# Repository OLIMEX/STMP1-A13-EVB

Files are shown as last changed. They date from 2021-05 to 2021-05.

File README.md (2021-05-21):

# STMP1-A13-EVB
Evaluation board for STMP15x-SOM and A13-SOM System on modules

Product page: https://www.olimex.com/Products/SOM/STMP1/STMP1-A13--EVB/open-source-hardware

## License
* Hardware is released under CERN OHL v1.2 license
* Software is released under GPL3 License
* Documentation is released under CC BY-SA 3.0

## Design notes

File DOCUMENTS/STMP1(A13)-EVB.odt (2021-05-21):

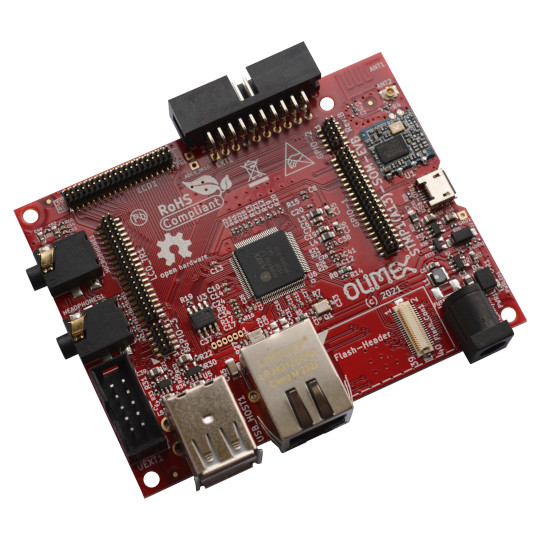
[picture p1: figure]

STMP1(A13)-EVB

User Manual

Rev.1.0 May 2021

olimex.com

# Overview

STMP1 (https://www.olimex.com/Products/SOM/STMP1/STMP1-A13--EVB/open-source-hardware)(A13) (https://www.olimex.com/Products/SOM/STMP1/STMP1-A13--EVB/open-source-hardware)- (https://www.olimex.com/Products/SOM/STMP1/STMP1-A13--EVB/open-source-hardware)EVB (https://www.olimex.com/Products/SOM/STMP1/STMP1-A13--EVB/open-source-hardware) is evaluation board for STMP15x-SOM (https://www.olimex.com/Products/SOM/STMP1/STMP157-SOM-512/) or A13-SOM (https://www.olimex.com/Products/SOM/A13/) System On Module running Linux mainline Kernel and Uboot on ST Microelectronics industrial grade Dual Core Cortex-A7 ARM SOC.

As A13-SOM (https://www.olimex.com/Products/SOM/A13/) and STMP15x-SOM (https://www.olimex.com/Products/SOM/STMP1/STMP157-SOM-512/) share same pinout this evaluation board is suitable also for A13-SOM (https://www.olimex.com/Products/SOM/A13/) System On Module.

Top view:

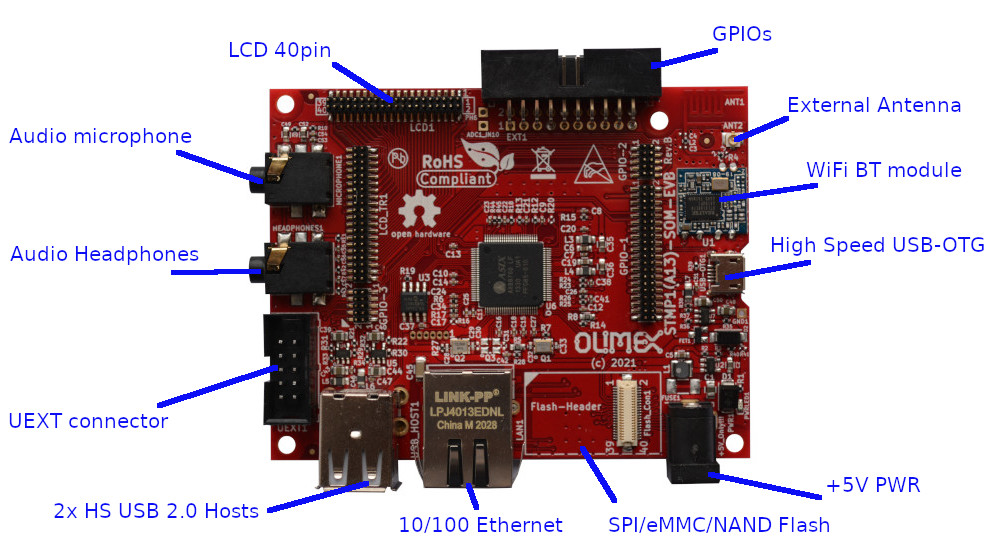
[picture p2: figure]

## General information

STM32MP15X (https://www.st.com/en/microcontrollers-microprocessors/stm32mp1-series.html) SOC are Dual-core Arm Cortex-A7 running up to 800 MHz and Cortex-M4 at 209 MHz combined with a LCD interface, dedicated 3D graphics processing unit (GPU).

STMP1 (https://www.olimex.com/Products/SOM/STMP1/STMP1-A13--EVB/open-source-hardware)(A13) (https://www.olimex.com/Products/SOM/STMP1/STMP1-A13--EVB/open-source-hardware)- (https://www.olimex.com/Products/SOM/STMP1/STMP1-A13--EVB/open-source-hardware)EV (https://www.olimex.com/Products/SOM/STMP1/STMP1-A13--EVB/open-source-hardware)B (https://www.olimex.com/Products/SOM/STMP1/STMP151-SOM-256/) demo evaluation board is produced only in commercial temperature grade 0-70C.

## Order codes

STMP1 (https://www.olimex.com/Products/SOM/STMP1/STMP1-A13--EVB/open-source-hardware)(A13) (https://www.olimex.com/Products/SOM/STMP1/STMP1-A13--EVB/open-source-hardware)- (https://www.olimex.com/Products/SOM/STMP1/STMP1-A13--EVB/open-source-hardware)EV (https://www.olimex.com/Products/SOM/STMP1/STMP1-A13--EVB/open-source-hardware)B (https://www.olimex.com/Products/SOM/STMP1/STMP151-SOM-256/) only evaluation board for STMP15x-SOM (https://www.olimex.com/Products/SOM/STMP1/STMP157-SOM-512/) or A13-SOM (https://www.olimex.com/Products/SOM/A13/), does not include SOM module which have to be bough separately

## STMP1(A13)-EVB Features

- 0.05 inch (1.27 mm) connectors for STMP15x-SOM (https://www.olimex.com/Products/SOM/STMP1/STMP157-SOM-512/) or A13-SOM (https://www.olimex.com/Products/SOM/A13/)
- Two High Speed USB 2.0 Hosts
- High Speed USB 2.0 OTG
- 10/100Mb Ethernet connector
- WiFi / Bluetooth module with PCB antenna and option for external antenna
- Flash module connector for: SPI, eMMC, NAND Flash options
- 3.5mm Audio jack for microphone
- 3.5mm Audio jack for headphones
- UEXT connector
- GPIO connector
- 40 pin 0.05 inch (1.27 mm) step connector compatible with LCD-OLinuXino
- Power supply connector 5VDC

# Power supply

STMP1 (https://www.olimex.com/Products/SOM/STMP1/STMP1-A13--EVB/open-source-hardware)(A13) (https://www.olimex.com/Products/SOM/STMP1/STMP1-A13--EVB/open-source-hardware)- (https://www.olimex.com/Products/SOM/STMP1/STMP1-A13--EVB/open-source-hardware)E (https://www.olimex.com/Products/SOM/STMP1/STMP1-A13--EVB/open-source-hardware)VB (https://www.olimex.com/Products/SOM/STMP1/STMP1-A13--EVB/open-source-hardware) requires +5V, 0.2A to operate.

Do not apply more than 5V as this would damage the board.

Power consumption (including SOM module) is:

- around 0.4 A during boot
- around 0.6A when working at full speed
- around 1.2A when working at full speed and charge the LiPo battery

# Connectors

## LCD

RGB LCD signals and I2C connector to digital touch panel interface.

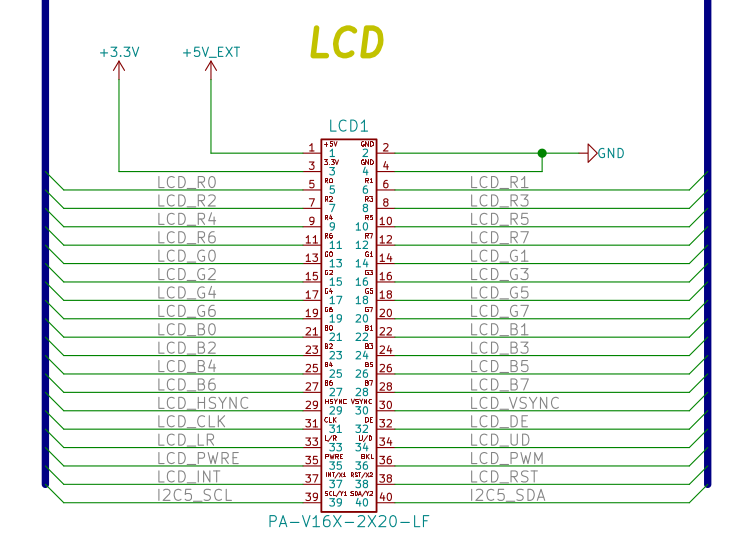
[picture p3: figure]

## GPIO

Right angle 20 pin connector with 2x I2C, UART, SDMMC, 2 GPIO, NRST, +3.3V and GND.

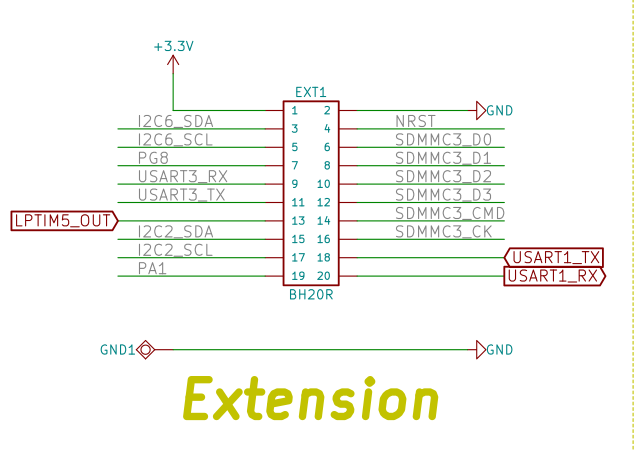
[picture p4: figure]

## UEXT

UEXT (https://www.olimex.com/Products/Modules/) connector for attaching different modules and sensors to SPI, UART, I2C:

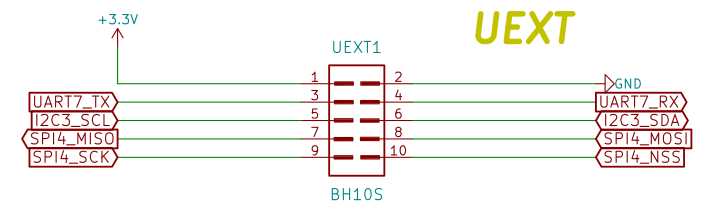
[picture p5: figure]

# Revision History

Revision 1.0 May 2021

# Contact information

Headquarters and Factory address:

OLIMEX Ltd

ul. Pravda 2

Plovdiv 4000

BULGARIA

Sales: sales@olimex.com

Technical Support: support@olimex.com

Corporate Website: www.olimex.com

For latest news and developments - follow our

- Blog (https://olimex.wordpress.com/)
- GitHub (https://github.com/OLIMEX)
- Twitter (https://twitter.com/olimex)
- Facebook (https://www.facebook.com/OLINUXINO/)
- Mastodon (https://mastodon.social/@olimex)
- Pluspora (https://pluspora.com/people/604855503b7f01377c23005056264835)
- IRC (https://webchat.freenode.net/#olimex)
- flicr (https://www.flickr.com/photos/olimex/)

11 STMP1(A13)-EVB Rev 1.0 www.olimex.com

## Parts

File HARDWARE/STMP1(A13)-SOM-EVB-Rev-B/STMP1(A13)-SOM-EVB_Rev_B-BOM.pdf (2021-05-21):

01/18/2021 | STMP1(A13)-SOM-EVB_Rev_B-BOM | 13:04:04
Quantity | Designation | Package | Designator
1 | 0R/R0402(Default_1-2_Populated) | R0402 | R4
1 | 0R/R0402 | L0402 | L2
5 | 22R/R0402 | R0402 | R11,R19,R42,R43,R45
4 | 49.9R/1%/R0402 | R0402 | R23,R24,R25,R26
2 | 330R/R0402 | R0402 | R27,R28
1 | 680R/1%/R0402 | R0402 | R6
1 | 1.1k/1%/R0402 | R0402 | R3
4 | 2.2k/R0402 | R0402 | R1,R9,R10,R44
5 | 4.7k/R0402 | R0402 | R15,R18,R33,R34,R38
1 | 4.99k/1%/R0402 | R0402 | R2
12 | 10k/R0402 | R0402 | R12,R13,R14,R17,R21,R22, R31,R32,R35,R37,R39,R40
2 | 12.1k/1%/R0603 | R0603 | R5,R8
3 | 13k/1%/R0402 | R0402 | R29,R30,R36
1 | 1M/R0402 | R0402 | R7
1 | 2.2uH/1.5A/DCR=72mR/ 20%/3.00x3.00x1.50mm/ CD32(NR3015T2R2M) | CD32 | L1
5 | FB0805/600R/2A | L0805 | L3,L4,L5,L6,L7
4 | 33pF/50V/5%/COG/C0402 | C0402 | C28,C29,C32,C33
1 | 1nF/2000V/10%/X7R/C1206 | C1206 | C45
1 | 3.3nF/50V/10%/X5R/C0402 | C0402 | C54
32 | 100nF/10V/10%/X5R/C0402 | C0402 | C7,C8,C9,C10,C11,C12,C13,C14,C15,C16,C17,C18, C20,C21,C22,C23,C24,C25,C26,C27,C34,C37, C38,C41,C42,C46,C47,C51,C53,C55,C56,C57
8 | 10uF/6.3V/20%/X5R/C0603 | C0603 | C2,C5,C6,C19,C35,C36,C49,C52
7 | 47uF/6.3V/20%/X5R/C0805 | C0805 | C1,C39,C40,C43,C44,C48,C50
1 | 1N5822/SMA | SMA-KA | D2
1 | SMBJ6.0A | DO214AA | D1
1 | LED/Red/0603 | LED_0603 | PWRLED1
1 | WPM2015-3/TR | SOT23 | FET1
1 | AX88760LF(LQFP-100) | LQFP-100 | U6
1 | MOD-RL-UM12BS-8188ETV | 8188ETV | U1
1 | 93LC66C-I/SN(SO-8) | SO-8 | U3
3 | SY6280AAC(SOT23-5) | SOT-23-5 | U4,U5,U7
1 | SY8089AAAC(SOT23-5) | SOT-23-5 | U2
1 | Q12MHZ/20pF/10ppm/4P/3.2x2.5mm | TSX-3.2x2.5mm | Q2
1 | Q25MHZ/20pF/20ppm/4P/3.2x2.5mm | TSX-3.2x2.5mm | Q1
1 | DF12(3.0)-40DS-0.5V(86) | Flash_Con | Flash_Con1
1 | BH10S | BH10S | UEXT1
1 | BH20R | BH20R | EXT1
1 | MICRO_USB\MISB-SWMM-5B_LF | MISB-SWMM-5B_LF | USB-OTG1
2 | PA-V16X-2X5-LF | PA-V16X-2X5-LF | GPIO-2,GPIO-3
3 | PA-V16X-2X20-LF | PA-V16X-2X20-LF | GPIO-1,LCD_TR1,LCD1
1 | PWRJ-2mm(YDJ-1134) | PWRJ-2mm | PWR1
1 | RJLD-060TC1(LPJ4013EDNL) | RJLBC-060TC1 | LAN1
2 | SCJ325P00XG0B02G | SCJ325P00XG0B02G | MICROPHONE1,HEADPHONES1
1 | USBB1-FRWH-4A(USB-Ax2) | USB_TWO_LEVEL | USB_HOST1
1 | U.FL-R-SMT-1 | U.FL-R-SMT-1 | ANT2
2 | NA/R0402 | R0402 | R16,R41
1 | NA(10k/R0402) | R0402 | R20
2 | NA/C0402 | C0402 | C3,C4
2 | NA(33pF/50V/5%/COG/C0402) | C0402 | C30,C31
1 | NA(5025) | FUSE-5025 | FUSE1
1 | NA(Q12MHZ/20pF/ 10ppm/4P/3.2x2.5mm) | TSX-3.2x2.5mm | Q3
1 | NA(WU06S) | WU06S | PGM1
1 | WIFI_ANT | WIFI_ANT | ANT1

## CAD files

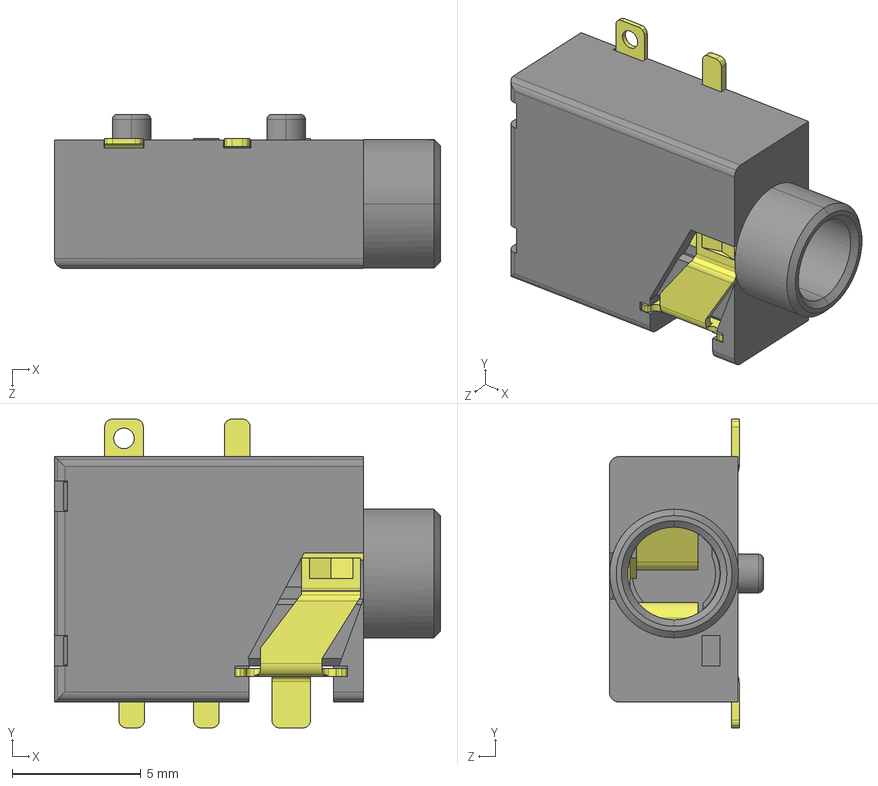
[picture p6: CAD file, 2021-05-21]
HARDWARE/STMP1(A13)-SOM-EVB-Rev-B/3d/Audio_Jack-3.5mm---CUI_SJ1-3515-SMT-TR.step
15.0 x 12.0 x 6.00 mm

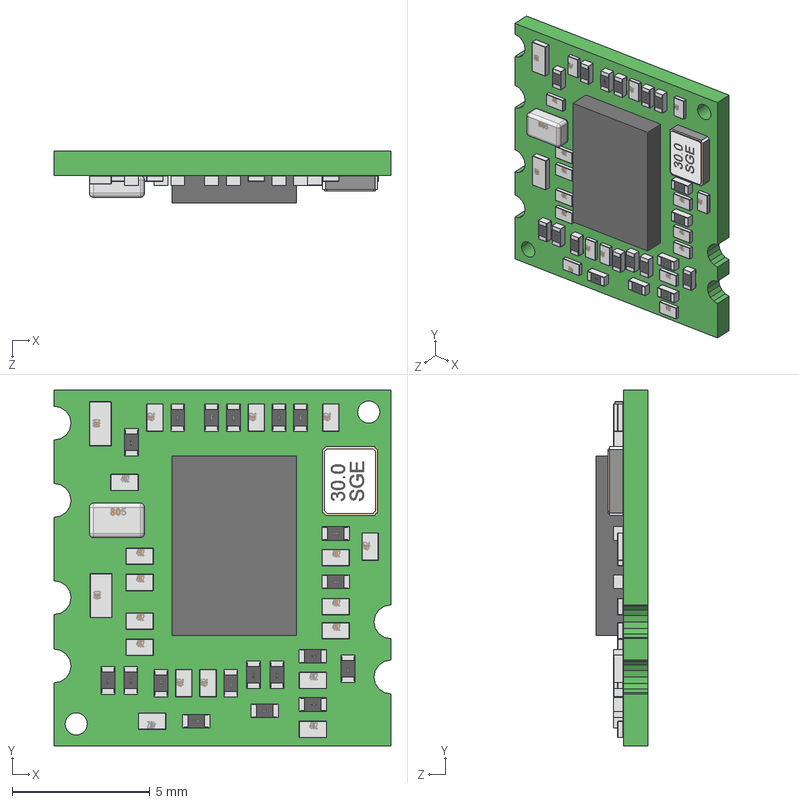
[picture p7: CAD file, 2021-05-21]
HARDWARE/STMP1(A13)-SOM-EVB-Rev-B/3d/RL-UM12BS-8188ETV.STEP
12.2 x 12.9 x 1.89 mm
Board
CAP0402 x 17
RES0402 x 19
CAP0603 x 2
CAP0805
SX-2520
Extruded

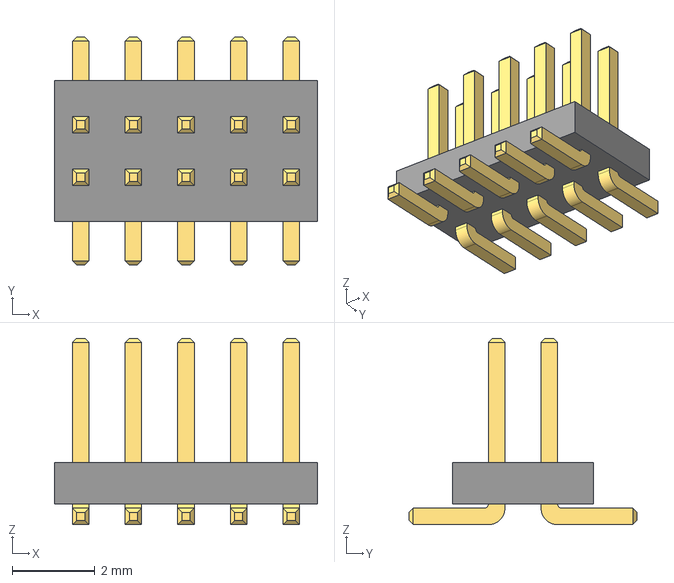
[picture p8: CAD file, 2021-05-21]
HARDWARE/STMP1(A13)-SOM-EVB-Rev-B/3d/Pin_Header_Straight_2x05_1.27mm.step
6.35 x 5.50 x 4.50 mm

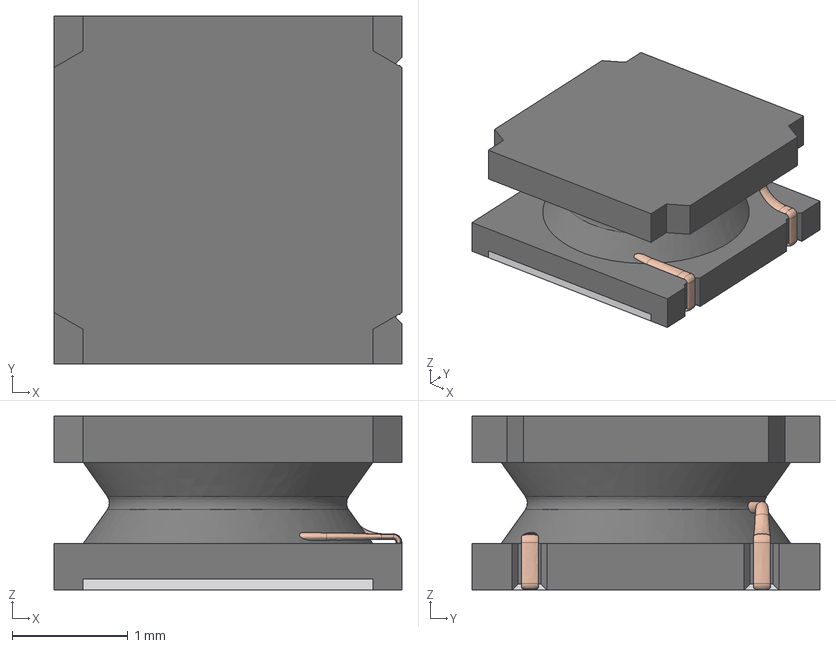
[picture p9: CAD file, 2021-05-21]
HARDWARE/STMP1(A13)-SOM-EVB-Rev-B/3d/L-CD32_shielded.step
3.00 x 3.00 x 1.50 mm

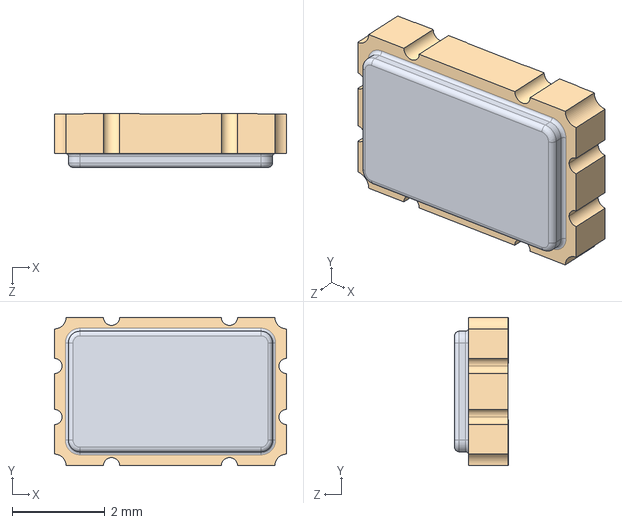
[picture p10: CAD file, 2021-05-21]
HARDWARE/STMP1(A13)-SOM-EVB-Rev-B/3d/QSG5032.step
5.00 x 3.20 x 1.16 mm

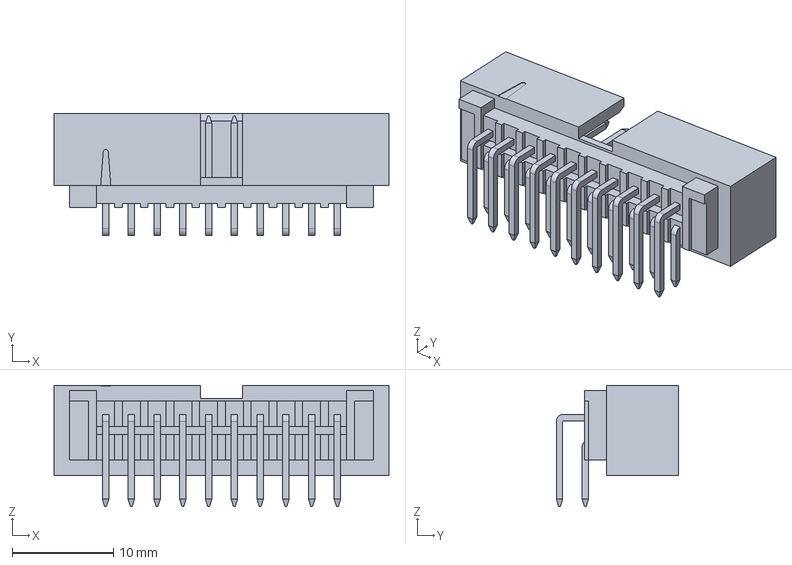
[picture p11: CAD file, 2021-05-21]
HARDWARE/STMP1(A13)-SOM-EVB-Rev-B/3d/BH20R_Molex---702472054.stp
33.0 x 12.1 x 11.9 mm

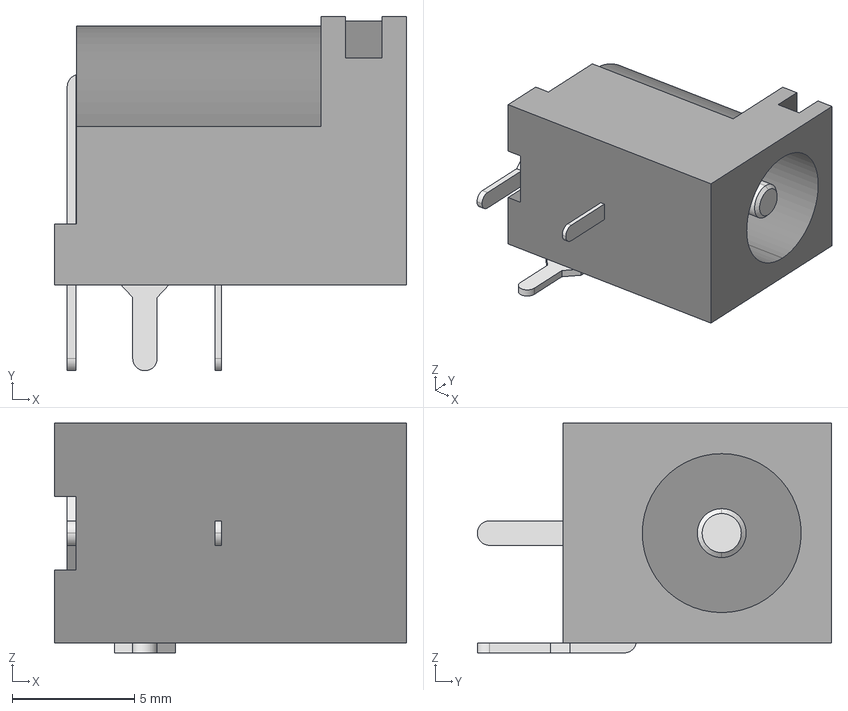
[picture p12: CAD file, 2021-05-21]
HARDWARE/STMP1(A13)-SOM-EVB-Rev-B/3d/pj-102ah.stp
14.4 x 14.5 x 9.40 mm

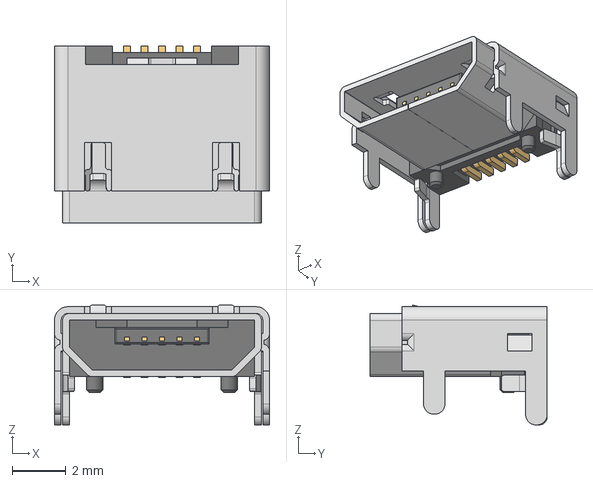
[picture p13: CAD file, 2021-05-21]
HARDWARE/STMP1(A13)-SOM-EVB-Rev-B/3d/usb_micro_4p.stp
8.00 x 6.60 x 4.46 mm

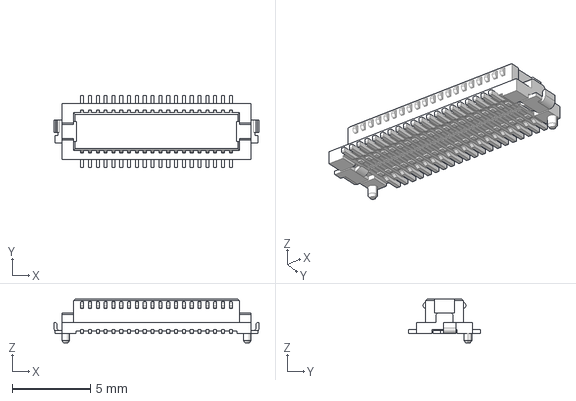
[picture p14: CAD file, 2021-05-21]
HARDWARE/STMP1(A13)-SOM-EVB-Rev-B/3d/DF12(3.0)-40DS-0.5V.stp
13.1 x 4.60 x 2.80 mm

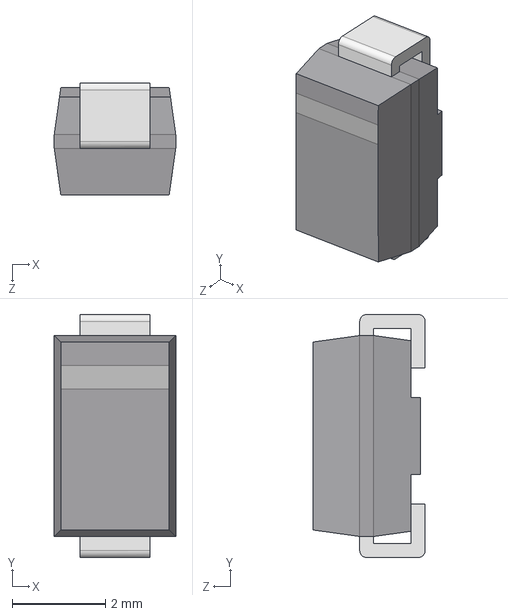
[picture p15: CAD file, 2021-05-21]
HARDWARE/STMP1(A13)-SOM-EVB-Rev-B/3d/DO-214AC_SMA.step
2.60 x 5.20 x 2.40 mm

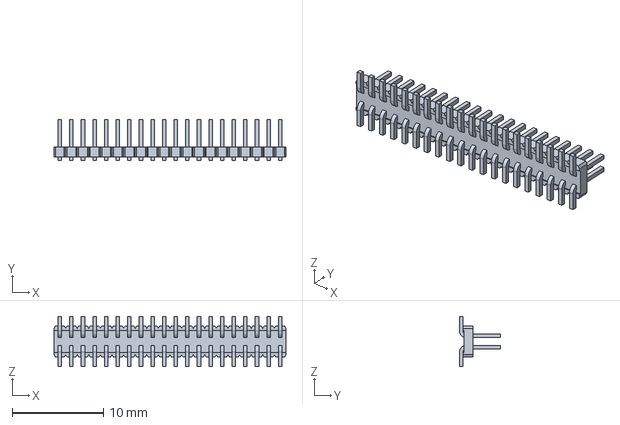
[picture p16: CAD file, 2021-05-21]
HARDWARE/STMP1(A13)-SOM-EVB-Rev-B/3d/40PinMaleSMD.stp
25.4 x 4.50 x 5.50 mm

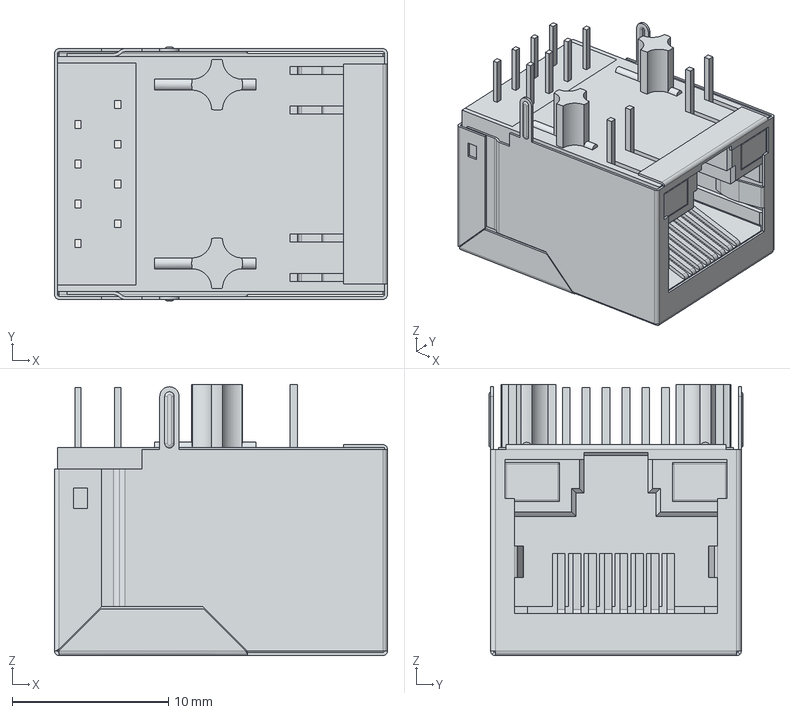
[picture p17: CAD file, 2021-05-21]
HARDWARE/STMP1(A13)-SOM-EVB-Rev-B/3d/Connector_1Port_RJ45_Magjack_10-100Base-T_AutoMDIX_Wurth_Electronics-7499010441.stp
21.3 x 16.2 x 17.4 mm
Shielding
Insulator 3
Insulator 1
Insulator 2
Green_Yellow_LED x 2

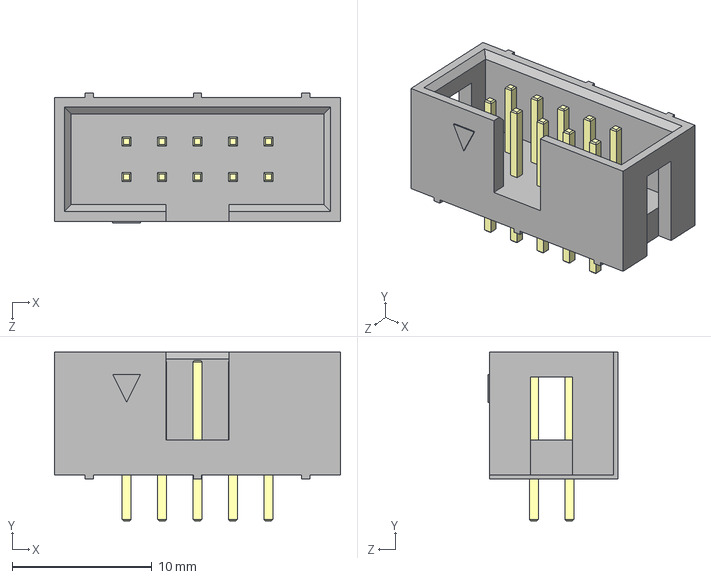
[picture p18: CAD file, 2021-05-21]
HARDWARE/STMP1(A13)-SOM-EVB-Rev-B/3d/BH-10__64.step
20.5 x 12.1 x 9.30 mm

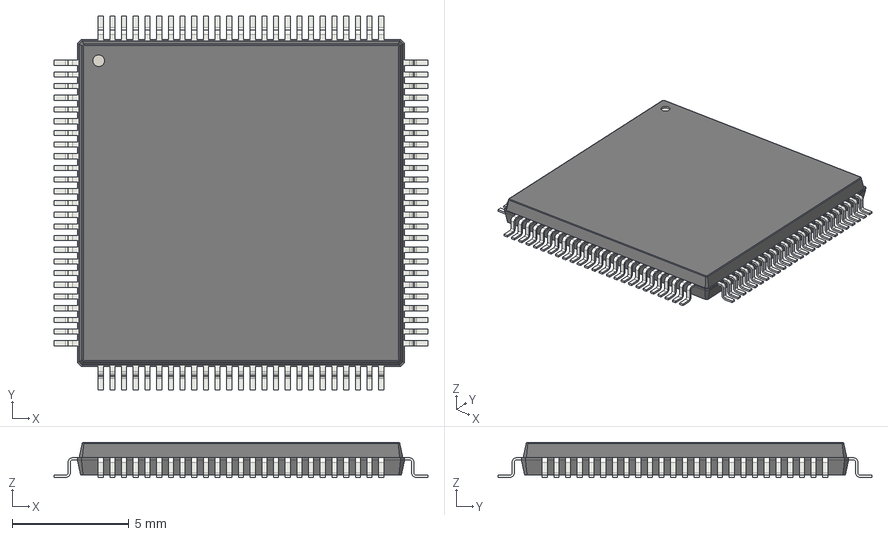
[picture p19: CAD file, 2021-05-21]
HARDWARE/STMP1(A13)-SOM-EVB-Rev-B/3d/LQFP-100_14x14mm_P0.5mm.step
16.0 x 16.0 x 1.50 mm

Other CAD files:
HARDWARE/STMP1(A13)-SOM-EVB-Rev-B/3d/USBB1-FRWH-4A(USB-Ax2)---CUI_DEVICES_UJ2-ADH-1-TH.step
HARDWARE/STMP1(A13)-SOM-EVB-Rev-B/3d/SOT-23.step
HARDWARE/STMP1(A13)-SOM-EVB-Rev-B/3d/SO-8_150mil---SN65HVDA1050AQDRQ1.STEP
HARDWARE/STMP1(A13)-SOM-EVB-Rev-B/3d/DO-214AA_SMB.step
HARDWARE/STMP1(A13)-SOM-EVB-Rev-B/3d/SOT-23-5.step
HARDWARE/STMP1(A13)-SOM-EVB-Rev-B/3d/U_FL-R-SMT-1.step

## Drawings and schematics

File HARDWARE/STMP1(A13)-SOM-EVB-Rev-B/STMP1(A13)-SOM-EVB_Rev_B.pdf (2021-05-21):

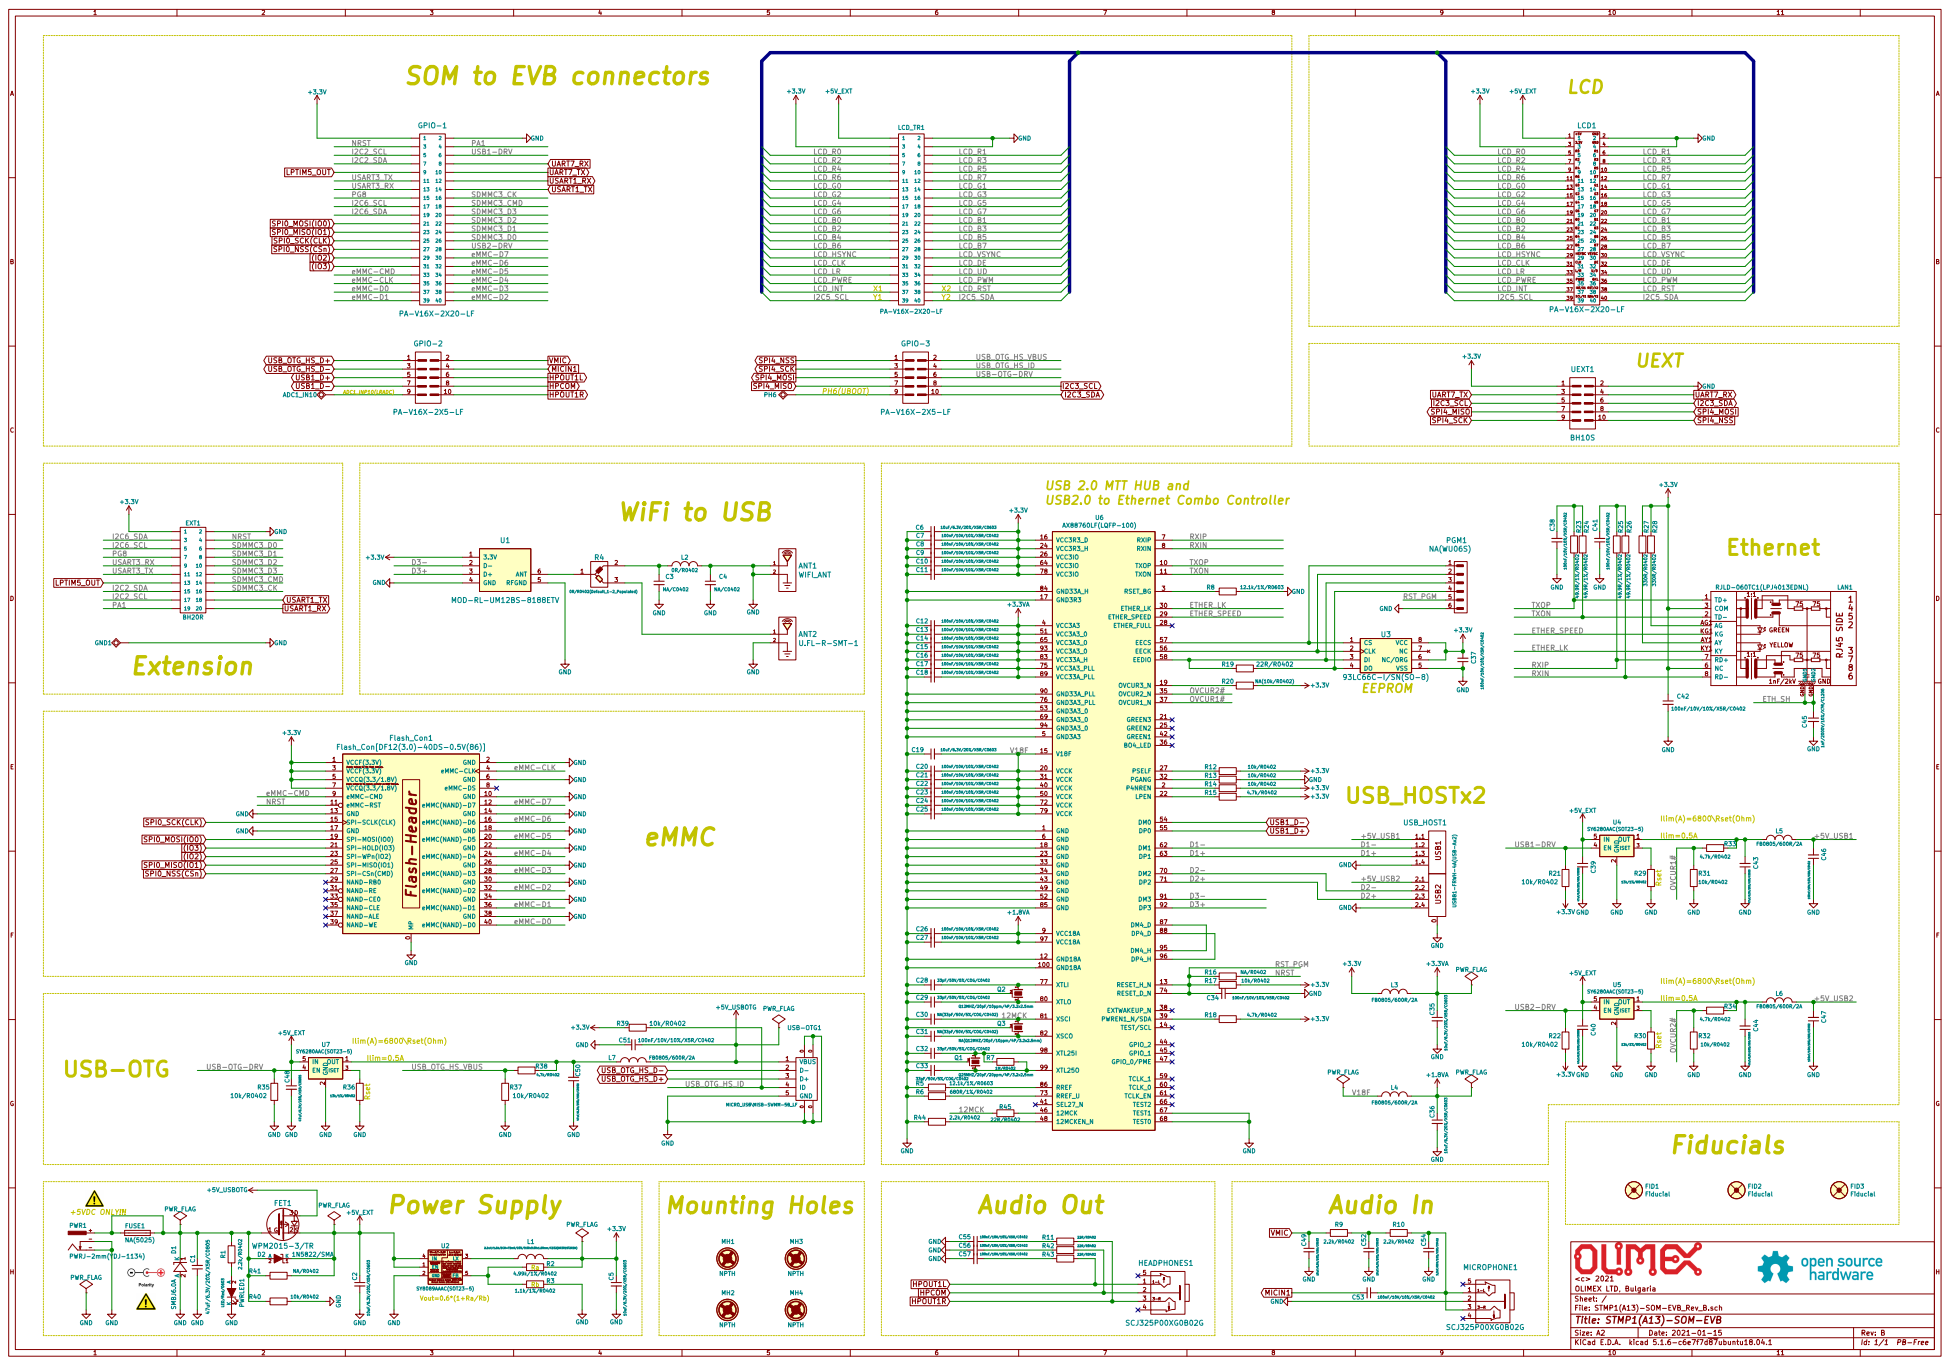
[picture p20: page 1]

SOM to EVB connectors
9GPIO-1 PA-V16X-2X20-LF

9 GPIO-3 PA-V16X-2X5-LF GND GND GND GND GND GND GND GND

USB 2.0 MTT HUB and USB2.0 to Ethernet Combo Controller

Ilim(A)=6800\Rset(Ohm) Rset

Ilim(A)=6800\Rset(Ohm) Audio Out

1 2 Q2 3 Q12MHZ/20pF/10ppm/4P/3.2x2.5mm C30 NA(33pF/50V/5%/COG/C0402) C31 NA(33pF/50V/5%/COG/C0402) 1 2 Q3 3 NA(Q12MHZ/20pF/10ppm/4P/3.2x2.5mm) C32 33pF/50V/5%/COG/C0402 C33

load current capability! Lx=2.2uH

Do not float. Enable control. FB Input Current, I(FB)=50nA(max) Feedback Reference Voltage, V(REF)=0.6V

File: STMP1(A13)-SOM-EVB_Rev_B.sch Sheet: / OLIMEX LTD, Bulgaria <c> 2021

Id: 1/1 PB-Free Title: STMP1(A13)-SOM-EVB

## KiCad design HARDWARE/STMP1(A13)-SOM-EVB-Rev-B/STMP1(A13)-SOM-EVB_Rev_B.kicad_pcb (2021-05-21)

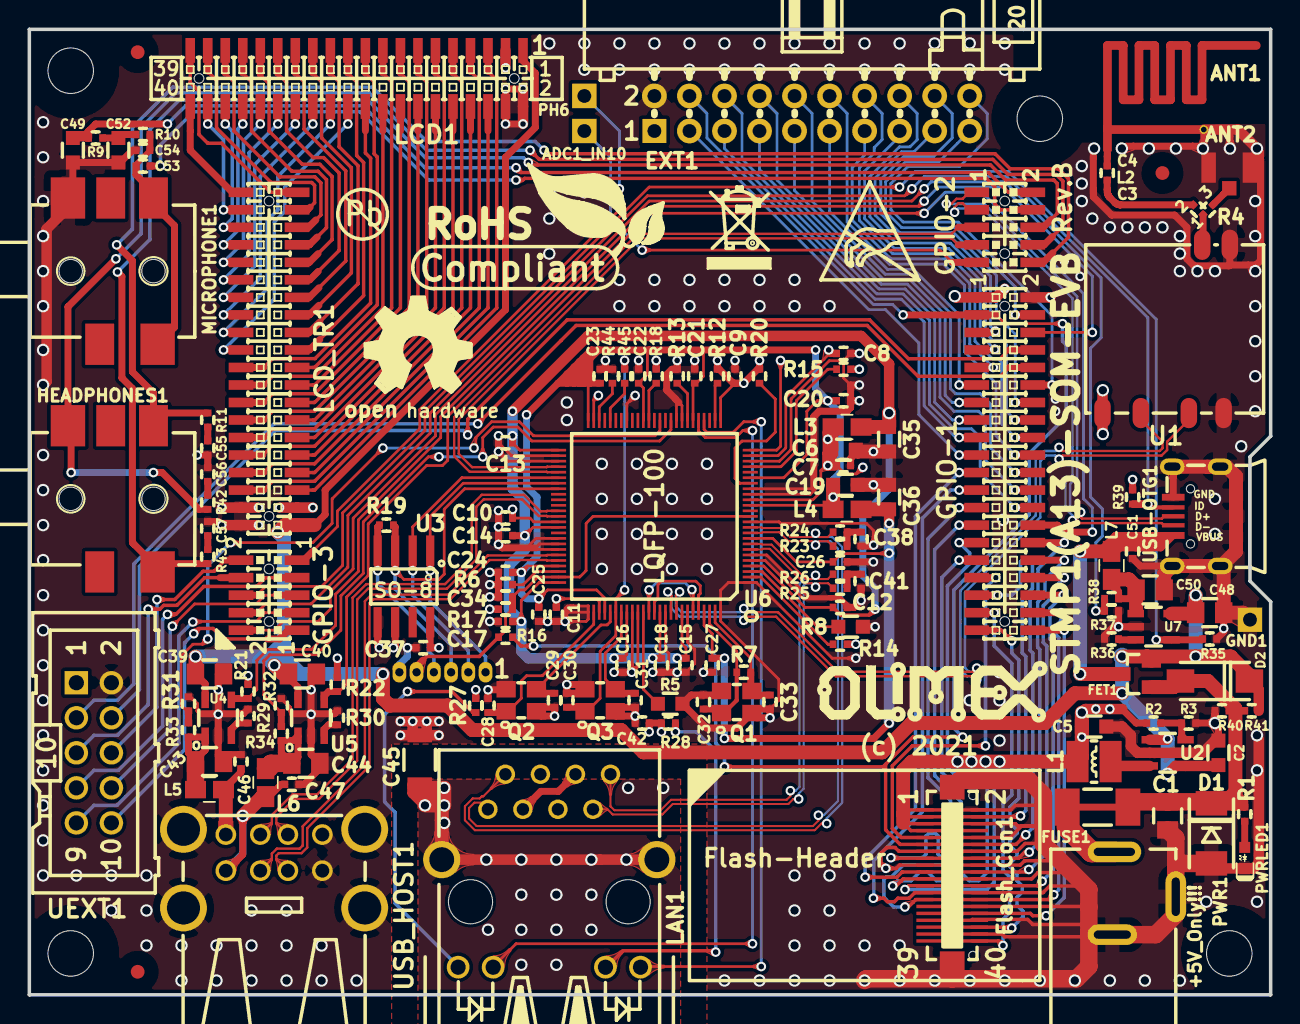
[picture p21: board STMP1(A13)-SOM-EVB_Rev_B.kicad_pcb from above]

Board: 4 copper layers, 90.0 x 70.0 mm, 157 parts (1 on the bottom side), 164 nets.

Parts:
ADC1_IN10: TESTPAD; TEST_PAD40x70_SQUARE
ANT1: WIFI_ANT; WIFI_ANT_ESP8266_ANT(1)_GND(2)_NO_MASK
ANT2: U.FL-R-SMT-1
C1, C39, C40, C43, C44, C48, C50: 47uF/6.3V/20%/X5R/C0805; C_0805_5MIL_DWS
C2, C5, C6, C19, C35, C36, C49, C52: 10uF/6.3V/20%/X5R/C0603; C_0603_5MIL_DWS
C3, C4: NA/C0402; C_0402_5MIL_DWS
C7, C8, C9, C10, C11, C12, C13, C14, C15, C16, C17, C18, C20, C21, C22, C23, C24, C25, C26, C27, C34, C37, C38, C41, C42, C46, C47, C51, C53, C55, C56, C57: 100nF/10V/10%/X5R/C0402; C_0402_5MIL_DWS
C28, C29, C32, C33: 33pF/50V/5%/COG/C0402; C_0402_5MIL_DWS
C30, C31: NA(33pF/50V/5%/COG/C0402); C_0402_5MIL_DWS
C45: 1nF/2000V/10%/X7R/C1206; C_1206_5MIL_DWS_ISO
C54: 3.3nF/50V/10%/X5R/C0402; C_0402_5MIL_DWS
D1: SMBJ6.0A; DO214AA_1(K)-2(A)
D2: 1N5822/SMA; SMA-KA
EXT1: BH20R
FET1: WPM2015-3/TR; SOT23
FID1, FID2, FID3: Fiducial; Fiducial1x3
FUSE1: NA(5025); FUSE-5025
Flash_Con1: Flash_Con[DF12(3.0)-40DS-0.5V(86)]
GND1: TESTPAD; TEST_PAD40x70_SQUARE
GPIO-1: PA-V16X-2X20-LF; GPH127SMT-02X20(PA-V16X-2X20-LF)
GPIO-2, GPIO-3: PA-V16X-2X5-LF; GPH127SMT-02X05(PA-V16X-2X5-LF)
HEADPHONES1: SCJ325P00XG0B02G
L1: 2.2uH/1.5A/DCR=72mR/20%/3.00x3.00x1.50mm/CD32(NR3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; CD32
L2: 0R/R0402; L_0402_5MIL_DWS
L3, L4, L5, L6, L7: FB0805/600R/2A; L_0805_5MIL_DWS
LAN1: RJLD-060TC1(LPJ4013EDNL); RJLBC-060TC1
LCD1: PA-V16X-2X20-LF; GPH127SMT-02X20(PA-V16X-2X20-LF)
LCD_TR1: PA-V16X-2X20-LF; GPH127SMT-02X20(PA-V16X-2X20-LF)
Logo_OSHW: LOGO_OPENHARDWARE_8x8
Logo_Olimex: OLIMEX_LOGO_TB
MH1, MH2, MH3, MH4: NPTH; Mounting_Hole_Drill-3.3mm_Clerance-7mm
MICROPHONE1: SCJ325P00XG0B02G
PGM1: NA(WU06S); WU06S
PH6: TESTPAD; TEST_PAD40x70_SQUARE
PWR1: PWRJ-2mm(YDJ-1134)
PWRLED1: LED/Red/0603; LED_0603_KA
Q1: Q25MHZ/20pF/20ppm/4P/3.2x2.5mm; TSX-3.2x2.5mm_GND(3)
Q2: Q12MHZ/20pF/10ppm/4P/3.2x2.5mm; TSX-3.2x2.5mm_GND(3)
Q3: NA(Q12MHZ/20pF/10ppm/4P/3.2x2.5mm); TSX-3.2x2.5mm_GND(3)
R1, R9, R10, R44: 2.2k/R0402; R_0402_5MIL_DWS
R2: 4.99k/1%/R0402; R_0402_5MIL_DWS
R3: 1.1k/1%/R0402; R_0402_5MIL_DWS
R4: 0R/R0402(Default_1-2_Populated); ANT_SWITCH-R0402
R5, R8: 12.1k/1%/R0603; R_0603_5MIL_DWS
R6: 680R/1%/R0402; R_0402_5MIL_DWS
R7: 1M/R0402; R_0402_5MIL_DWS
R11, R19, R42, R43, R45: 22R/R0402; R_0402_5MIL_DWS
R12, R13, R14, R17, R21, R22, R31, R32, R35, R37, R39, R40: 10k/R0402; R_0402_5MIL_DWS
R15, R18, R33, R34, R38: 4.7k/R0402; R_0402_5MIL_DWS
R16, R41: NA/R0402; R_0402_5MIL_DWS
R20: NA(10k/R0402); R_0402_5MIL_DWS
R23, R24, R25, R26: 49.9R/1%/R0402; R_0402_5MIL_DWS
R27, R28: 330R/R0402; R_0402_5MIL_DWS
R29, R30, R36: 13k/1%/R0402; R_0402_5MIL_DWS
Sign_Antistatic: Val**; LOGO_ANTISTATIC_1
Sign_PB-Free: LOGO_PBFREE
Sign_RecycleBin: LOGO_RECYCLEBIN_1
Sign_RoHS: Val**; LOGO_ROHS_1
U1: MOD-RL-UM12BS-8188ETV
U2: SY8089AAAC(SOT23-5); SOT-23-5
U3: 93LC66C-I/SN(SO-8); SO-8
U4, U5, U7: SY6280AAC(SOT23-5); SOT-23-5
U6: AX88760LF(LQFP-100); LQFP-100_Pitch-0.4mm_Dimensions-12.00x12.00x1.60mm
UEXT1: BH10S
USB-OTG1: MICRO_USB\MISB-SWMM-5B_LF; USB-MICRO_MISB-SWMM-5B_LF
USB_HOST1: USBB1-FRWH-4A(USB-Ax2); USB_TWO_LEVEL

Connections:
(IO2): Flash_Con1.23, GPIO-1.29
(IO3): Flash_Con1.21, GPIO-1.31
+1.8VA: C26.1, C27.1, C36.1, L4.2, U6.9, U6.97
+3.3VA: C12.1, C13.1, C14.1, C15.1, C16.1, C17.1, C18.1, C35.1, L3.2, U6.4, U6.51, U6.65, U6.75, U6.83, U6.89, U6.93
+3V3: C5.1, C6.2, C7.1, C8.1, C9.1, C10.1, C11.1, C37.2, C42.1, EXT1.1, Flash_Con1.1, Flash_Con1.3, Flash_Con1.5, Flash_Con1.7, GPIO-1.1, L1.2, L3.1, LAN1.3, LAN1.6, LCD1.3, LCD_TR1.3, R2.2, R12.2, R14.2, R15.2, R17.2, R18.2, R20.2, R21.1, R22.1, R27.1, R28.1, R39.2, U1.1, U3.6, U3.8, U6.16, U6.24, U6.26, U6.64, U6.78, UEXT1.1
+5V_EXT: C2.1, C39.1, C40.1, C48.1, D2.1, FET1.2, LCD1.1, LCD_TR1.1, R41.1, U2.1, U2.4, U4.5, U5.5, U7.5
+5V_USBOTG: C51.1, FET1.3, L7.2, USB-OTG1.1
/12MCK: C30.1, Q3.1, R45.2, U6.81
/+5V_USB1: C46.2, L5.2, USB_HOST1.1.1
/+5V_USB2: C47.2, L6.2, USB_HOST1.2.1
/D1+: U6.63, USB_HOST1.1.3
/D1-: U6.62, USB_HOST1.1.2
/D2+: U6.71, USB_HOST1.2.3
/D2-: U6.70, USB_HOST1.2.2
/D3+: U1.3, U6.92
/D3-: U1.2, U6.91
/ETHER_LK: LAN1.KY1, U6.30
/ETHER_SPEED: LAN1.KG1, U6.29
/ETH_SH: C45.1, LAN1.GND1, LAN1.GND2
/I2C2_SCL: EXT1.17, GPIO-1.5
/I2C2_SDA: EXT1.15, GPIO-1.7
/I2C5_SCL: LCD1.39, LCD_TR1.39
/I2C5_SDA: LCD1.40, LCD_TR1.40
/I2C6_SCL: EXT1.5, GPIO-1.17
/I2C6_SDA: EXT1.3, GPIO-1.19
/LCD_B0: LCD1.21, LCD_TR1.21
/LCD_B1: LCD1.22, LCD_TR1.22
/LCD_B2: LCD1.23, LCD_TR1.23
/LCD_B3: LCD1.24, LCD_TR1.24
/LCD_B4: LCD1.25, LCD_TR1.25
/LCD_B5: LCD1.26, LCD_TR1.26
/LCD_B6: LCD1.27, LCD_TR1.27
/LCD_B7: LCD1.28, LCD_TR1.28
/LCD_CLK: LCD1.31, LCD_TR1.31
/LCD_DE: LCD1.32, LCD_TR1.32
/LCD_G0: LCD1.13, LCD_TR1.13
/LCD_G1: LCD1.14, LCD_TR1.14
/LCD_G2: LCD1.15, LCD_TR1.15
/LCD_G3: LCD1.16, LCD_TR1.16
/LCD_G4: LCD1.17, LCD_TR1.17
/LCD_G5: LCD1.18, LCD_TR1.18
/LCD_G6: LCD1.19, LCD_TR1.19
/LCD_G7: LCD1.20, LCD_TR1.20
/LCD_HSYNC: LCD1.29, LCD_TR1.29
/LCD_INT: LCD1.37, LCD_TR1.37
/LCD_LR: LCD1.33, LCD_TR1.33
/LCD_PWM: LCD1.36, LCD_TR1.36
/LCD_PWRE: LCD1.35, LCD_TR1.35
/LCD_R0: LCD1.5, LCD_TR1.5
/LCD_R1: LCD1.6, LCD_TR1.6
/LCD_R2: LCD1.7, LCD_TR1.7
/LCD_R3: LCD1.8, LCD_TR1.8
/LCD_R4: LCD1.9, LCD_TR1.9
/LCD_R5: LCD1.10, LCD_TR1.10
/LCD_R6: LCD1.11, LCD_TR1.11
/LCD_R7: LCD1.12, LCD_TR1.12
/LCD_RST: LCD1.38, LCD_TR1.38
/LCD_UD: LCD1.34, LCD_TR1.34
/LCD_VSYNC: LCD1.30, LCD_TR1.30
/NRST: EXT1.4, Flash_Con1.11, GPIO-1.3, R16.2
/OVCUR1#: R31.2, R33.1, U6.37
/OVCUR2#: R32.2, R34.1, U6.35
/PA1: EXT1.19, GPIO-1.4
/PG8: EXT1.7, GPIO-1.15
/RST_PGM: C34.2, PGM1.5, R16.1, R17.1, U6.13, U6.74
/RXIN: LAN1.8, R26.2, U6.8
/RXIP: LAN1.7, R25.2, U6.7
/SDMMC3_CK: EXT1.16, GPIO-1.16
/SDMMC3_CMD: EXT1.14, GPIO-1.18
/SDMMC3_D0: EXT1.6, GPIO-1.26
/SDMMC3_D1: EXT1.8, GPIO-1.24
/SDMMC3_D2: EXT1.10, GPIO-1.22
/SDMMC3_D3: EXT1.12, GPIO-1.20
/TXON: LAN1.2, R24.2, U6.11
/TXOP: LAN1.1, R23.2, U6.10
/USART3_RX: EXT1.9, GPIO-1.13
/USART3_TX: EXT1.11, GPIO-1.11
/USB1-DRV: GPIO-1.6, R21.2, U4.4
/USB2-DRV: GPIO-1.28, R22.2, U5.4
/USB-OTG-DRV: GPIO-3.6, R35.2, U7.4
/USB_OTG_HS_ID: GPIO-3.4, R39.1, USB-OTG1.4
/USB_OTG_HS_VBUS: GPIO-3.2, R37.2, R38.1
/V18F: C19.2, C20.1, C21.1, C22.1, C23.1, C24.1, C25.1, L4.1, U6.15, U6.20, U6.31, U6.40, U6.50, U6.72, U6.79
/eMMC-CLK: Flash_Con1.4, GPIO-1.35
/eMMC-CMD: Flash_Con1.9, GPIO-1.33
/eMMC-D0: Flash_Con1.40, GPIO-1.37
/eMMC-D1: Flash_Con1.36, GPIO-1.39
/eMMC-D2: Flash_Con1.32, GPIO-1.40
/eMMC-D3: Flash_Con1.28, GPIO-1.38
/eMMC-D4: Flash_Con1.24, GPIO-1.36
/eMMC-D5: Flash_Con1.20, GPIO-1.34
/eMMC-D6: Flash_Con1.16, GPIO-1.32
/eMMC-D7: Flash_Con1.12, GPIO-1.30
GND: ANT1.1, ANT1.2, ANT2.2, C1.1, C2.2, C3.2, C4.1, C4.2, C5.2, C6.1, C7.2, C8.2, C9.2, C10.2, C11.2, C12.2, C13.2, C14.2, C15.2, C16.2, C17.2, C18.2, C19.1, C20.2, C21.2, C22.2, C23.2, C24.2, C25.2, C26.2, C27.2, C28.2, C29.2, C30.2, C31.2, C32.2, C33.2, C34.1, C35.2, C36.2, C37.1, C38.1, C39.2, C40.2, C41.1, C42.2, C43.1, C44.1, C45.2, C46.1, C47.1, C48.2, C49.2, C50.1, C51.2, C52.2, C54.2, C55.2, C56.2, C57.2, D1.2, EXT1.2, Flash_Con1.0, Flash_Con1.2, Flash_Con1.6, Flash_Con1.10, Flash_Con1.13, Flash_Con1.14, Flash_Con1.17, Flash_Con1.18, Flash_Con1.22, Flash_Con1.26, Flash_Con1.30, Flash_Con1.34, Flash_Con1.38, GND1.1, GPIO-1.2, L2.2, LCD1.2, LCD1.4, LCD_TR1.2, LCD_TR1.4, MICROPHONE1.2, PGM1.6, PWR1.-, PWRLED1.1, Q1.3, Q2.3, Q3.3, R3.2, R5.1, R6.1, R8.2, R13.2, R29.1, R30.1, R31.1, R32.1, R35.1, R36.1, R37.1, R40.1, R44.2, U1.4, U1.5, U2.2, U3.5, U4.2, U5.2, U6.1, U6.5, U6.6, U6.12, U6.17, U6.18, U6.23, U6.33, U6.34, U6.43, U6.49, U6.52, U6.53, U6.67, U6.68, U6.69, U6.76, U6.84, U6.85, U6.90, U6.94, U6.100, U7.2, UEXT1.2, USB-OTG1.0, USB-OTG1.5, USB_HOST1.0, USB_HOST1.1.4, USB_HOST1.2.4
HPCOM: GPIO-2.8, HEADPHONES1.2, R42.2
HPOUT1L: GPIO-2.6, HEADPHONES1.1, R43.2
HPOUT1R: GPIO-2.10, HEADPHONES1.3, R11.2
I2C3_SCL: GPIO-3.8, UEXT1.5
I2C3_SDA: GPIO-3.10, UEXT1.6
LPTIM5_OUT: EXT1.13, GPIO-1.9
MICIN1: C53.2, GPIO-2.4
unnamed: ADC1_IN10.1, GPIO-2.9
unnamed: ANT2.1, R4.3
unnamed: C1.2, D1.1, D2.2, FET1.1, FUSE1.1, FUSE1.2, PWR1.+, R1.1, R40.2, R41.2
unnamed: C3.1, L2.1, R4.2
unnamed: C28.1, Q2.1, U6.77
unnamed: C29.1, Q2.2, U6.80
unnamed: C31.1, Q3.2, U6.82
unnamed: C32.1, Q1.1, R7.1, U6.98
unnamed: C33.1, Q1.2, R7.2, U6.99
unnamed: C38.2, R23.1, R24.1
unnamed: C41.2, R25.1, R26.1
unnamed: C43.2, L5.1, R33.2, U4.1
unnamed: C44.2, L6.1, R34.2, U5.1
unnamed: C50.2, L7.1, R38.2, U7.1
unnamed: C52.1, R9.1, R10.2
unnamed: C53.1, C54.1, MICROPHONE1.1, MICROPHONE1.3, R10.1
unnamed: C55.1, R11.1
unnamed: C56.1, R42.1
unnamed: C57.1, R43.1
unnamed: GPIO-3.9, PH6.1
unnamed: L1.1, U2.3
unnamed: LAN1.AG1, R28.2
unnamed: LAN1.AY1, R27.2
unnamed: PGM1.1, U3.1, U6.57
unnamed: PGM1.2, U3.2, U6.56
unnamed: PGM1.3, R19.1, U3.3, U6.58
unnamed: PGM1.4, R19.2, U3.4
unnamed: PWRLED1.2, R1.2
unnamed: R2.1, R3.1, U2.5
unnamed: R4.1, U1.6
unnamed: R5.2, U6.86
unnamed: R6.2, U6.73
unnamed: R8.1, U6.3
unnamed: R12.1, U6.27
unnamed: R13.1, U6.32
unnamed: R14.1, U6.2
unnamed: R15.1, U6.22
unnamed: R18.1, U6.39
unnamed: R20.1, U6.19
unnamed: R29.2, U4.3
unnamed: R30.2, U5.3
unnamed: R36.2, U7.3
unnamed: R44.1, U6.48
unnamed: R45.1, U6.46
unnamed: U6.87, U6.95
unnamed: U6.88, U6.96
SPI0_MISO(IO1): Flash_Con1.25, GPIO-1.23
SPI0_MOSI(IO0): Flash_Con1.19, GPIO-1.21
SPI0_NSS(CSn): Flash_Con1.27, GPIO-1.27
SPI0_SCK(CLK): Flash_Con1.15, GPIO-1.25
SPI4_MISO: GPIO-3.7, UEXT1.7
SPI4_MOSI: GPIO-3.5, UEXT1.8
SPI4_NSS: GPIO-3.1, UEXT1.10
SPI4_SCK: GPIO-3.3, UEXT1.9
UART7_RX: GPIO-1.8, UEXT1.4
UART7_TX: GPIO-1.10, UEXT1.3
USART1_RX: EXT1.20, GPIO-1.12
USART1_TX: EXT1.18, GPIO-1.14
USB1_D+: GPIO-2.5, U6.55
USB1_D-: GPIO-2.7, U6.54
USB_OTG_HS_D+: GPIO-2.1, USB-OTG1.3
USB_OTG_HS_D-: GPIO-2.3, USB-OTG1.2
VMIC: C49.1, GPIO-2.2, R9.2

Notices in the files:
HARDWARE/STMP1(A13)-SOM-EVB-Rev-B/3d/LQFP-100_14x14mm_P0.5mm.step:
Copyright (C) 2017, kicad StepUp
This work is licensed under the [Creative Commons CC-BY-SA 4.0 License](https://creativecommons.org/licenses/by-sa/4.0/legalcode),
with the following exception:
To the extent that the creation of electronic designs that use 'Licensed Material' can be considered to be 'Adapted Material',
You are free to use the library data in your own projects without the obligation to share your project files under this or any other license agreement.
